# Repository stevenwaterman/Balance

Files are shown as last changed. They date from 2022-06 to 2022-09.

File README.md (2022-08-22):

# Balance Box

I built a box that lets me publicly share how I'm feeling.

[Read the blog post for more info](https://stevenwaterman.uk/balance-box)

## Instructions

These are going to be fairly vague, because you probably shouldn't follow my instructions directly.
Feel free to get in touch if you need help.

### Tools

- Soldering Iron
- 3D Printer, min 20x12x12cm bed
- Multimeter, unless you're a sadist

### Parts

Generic things:

- Breadboard jumper wires, male-male and male-female
- Wire
- Solder
- (Recommended) TriPad stripboard
  - Use whatever you're comfortable with for wiring up the shift registers and the resistors
- Approx 300g printer filament
  - I used PETG for the case and PLA for the sliders, anything will work

These are just the parts I used, alternatives will work

- 1x Arduino Uno & USB Cable
- 3x SN74HC595N shift registers
- 3x LDS-C814RI 7-segment displays
- 3x PTB0143-2010BPB103 slide potentiometers
- 21x 273-158-RC resistor, 158 ohm, 1/2 watt
- 4x M6 bolts, 30mm-ish length

### Steps

*This is from memory, no guarantees. Skip to the 'Firebase' section if you just want the website part.*

**Electronics:**

1. Print all the pieces in the `printerFiles` folder. It will take about 24hrs in multiple runs.
1. Put the 3 shift registers with resistors on the outputs on the stripboard. See `circuit.svg`.
1. Use male-female jumper cables to connect from the stripboard to the display, or plug the display into more stripboard.
1. Use male-male jumper cables to connect the 3 logic pins of the shift register to the arduino.
1. Solder wires to the display cathodes, and potentiometer power pins.
1. Solder a male-male jumper cable to the potentiometer signal pin.
1. Place the components into the housing, and bolt the face plate on to hold it together. The bolts should self-tap into the plastic.
1. Connect all the negatives together, and all the positives together, and plug them into the Arduino with a jumper cable.
1. Plug the display in with the jumper cables from before. The order doesn't really matter, just make sure it's consistent between them.
1. Plug everything in to the Arduino.
1. Put the back case on, bolt everything together
1. Add the 3d-printed sliders on the potentiometers. If your printer is dialed in, they should push-fit nicely.

**Arduino:**

1. Plug in the Arduino, update the pin configs to match your setup, and flash the provided sketch.
1. Swap the `LED` constants around until the numbers display correctly. See [the datasheet](https://eu.mouser.com/datasheet/2/244/LUMX_S_A0001418642_1-2551748.pdf) for a segment label reference.
1. Check that everything is working and you can see the current score in the Serial Monitor.

**Firebase:**

1. Create a [Firebase](https://console.firebase.google.com/) account and a new project.
1. Under the project settings, download the service account key, and save it as `credentials.json` in the root of this repository.
1. In the project settings, add a web app, and copy the `firebaseConfig` out of the `npm` SDK setup and configuration, into [web/src/lib/initFirebase.ts](https://github.com/stevenwaterman/Balance/blob/03ef952fb352bc81930753e494502babe5fda147/web/src/lib/initFirebase.ts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).
1. Enable Authentication.
1. Enable the Google sign-in provider for authentication
1. Add your domain (eg `stevenwaterman.uk` or `stevenwaterman.github.io` etc) to the `Authorized Domains` under `Settings`.
1. Enable Firestore.
1. Create three collections - `current`, `historic`, and `labels`.
1. Set the Firestore rules as:

```
rules_version = '2';
service cloud.firestore {
  match /databases/{database}/documents {
  	match /historic/{document=**} {
      allow read, write: if request.auth.uid == "sDV4cfFys0R5bapdvpeCTQSL9t32";
    }
    match /current/current {
      allow read: if true;
      allow write: if request.auth.uid == "sDV4cfFys0R5bapdvpeCTQSL9t32";
    }
    match /labels/{document=**} {
      allow read,write: if request.auth.uid == "sDV4cfFys0R5bapdvpeCTQSL9t32";
    }
  }
}
```

**Web:**

Start by forking this repository. It's mostly automated, other than a couple of bits of configuration.

1. Enable workflows under the `Actions` tab
1. In GitHub `Setting > Security > Secrets > Actions`, create a new Repository Secret named `FIREBASE_CREDENTIALS`. Copy the contents of the `credentials.json` file into the `Value` text box and save it.
1. If your repo is not called `Balance`, update the [base path](https://github.com/stevenwaterman/Balance/blob/03ef952fb352bc81930753e494502babe5fda147/web/svelte.config.js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) in `web/svelte.config.js`.
2. Update the fetch url with your GitHub username [in web/src/lib/dataSet.ts](https://github.com/stevenwaterman/Balance/blob/de5710807bf56cdf3094eda35e12951909dd7c2e/web/src/lib/dataSet.ts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)
3. The web app should automatically build, storing the static site in the `gh-pages` branch. You might have to give it permission to push to your repo.
4. Enable GitHub pages in the GitHub settings, selecting the `gh-pages` branch.
5. Wait for it to build, then go to `<YOUR_GH_USERNAME>.github.io/Balance` to verify it's all working.
6. Visit `<YOUR_GH_USERNAME>.github.io/Balance/control` and log in with google.
7. Visit the Firebase authentication page, and copy the UID for your use account.
8. Use that UID in the Firestore rules and update it [in web/src/routes/control.svelte](https://github.com/stevenwaterman/Balance/blob/03ef952fb352bc81930753e494502babe5fda147/web/src/routes/control.svelte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).

Wait for it to redeploy, and you should now be able to access the control page!

**Valid urls:**

- `/Balance`: Normal current-data display.
- `/Balance/graph`: Historic data display. Data updates once per day.
- `/Balance/control`: Data entry.

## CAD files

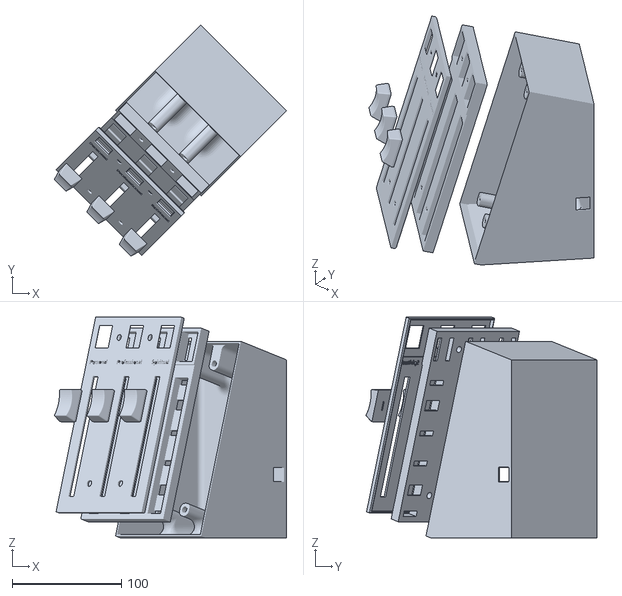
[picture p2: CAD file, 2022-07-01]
printerFiles/exploded.stl
212.1 x 211.0 x 201.9

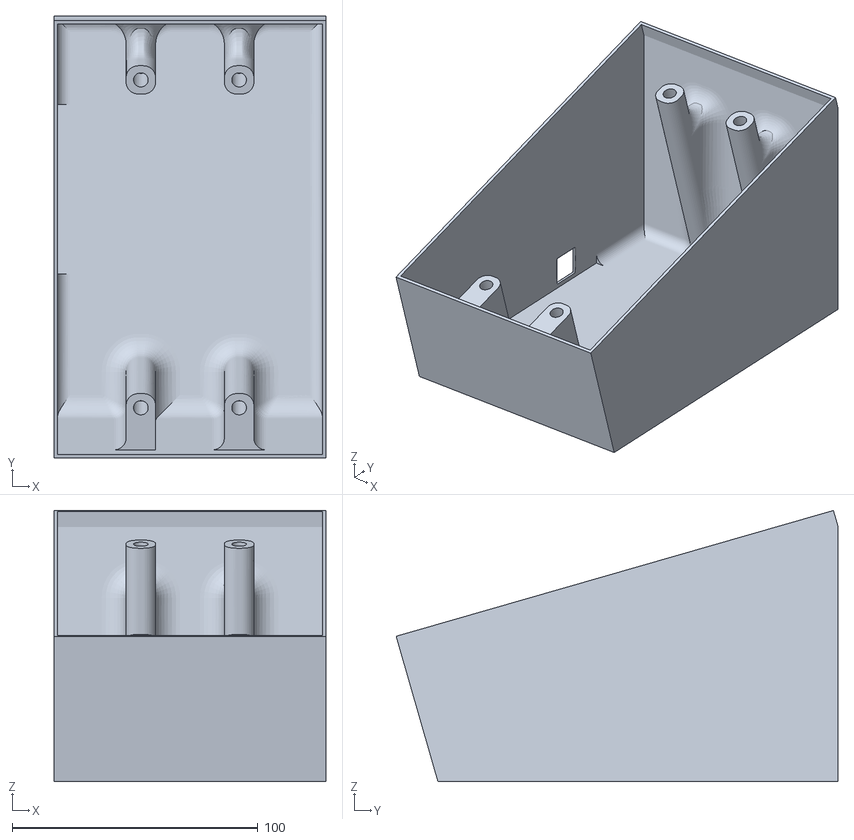
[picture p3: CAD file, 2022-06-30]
printerFiles/case.stl
110.7 x 179.8 x 110.3

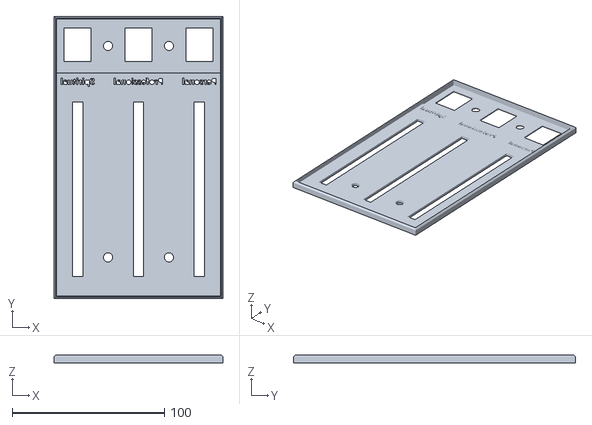
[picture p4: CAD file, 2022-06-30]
printerFiles/faceplate.stl
110.7 x 185.2 x 5.00

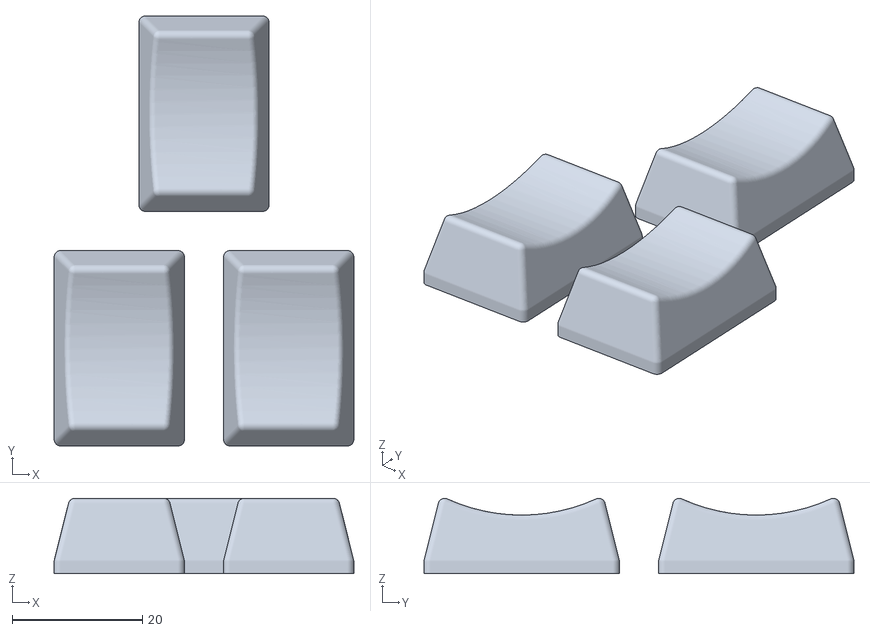
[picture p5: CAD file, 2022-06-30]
printerFiles/slider.stl
46.0 x 66.0 x 11.6

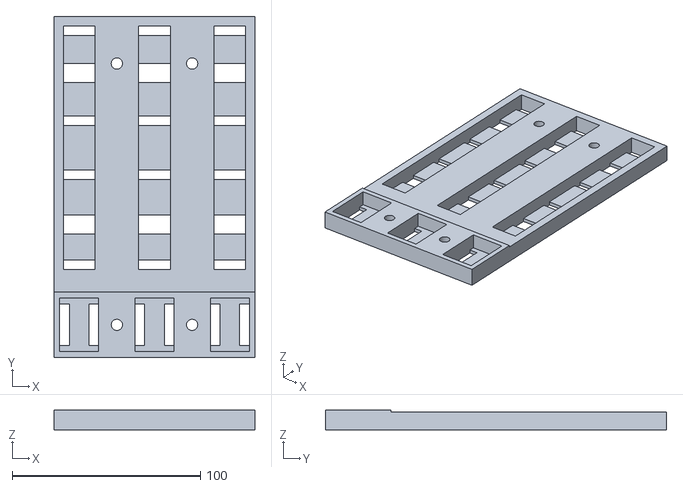
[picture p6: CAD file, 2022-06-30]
printerFiles/housing.stl
106.7 x 181.2 x 10.5

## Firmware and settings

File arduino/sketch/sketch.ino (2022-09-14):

int serenityLatch = 2;
int growthLatch = 5;
int belongingLatch = 8;

int serenityData = 3;
int growthData = 6;
int belongingData = 9;

int serenityClock = 4;
int growthClock = 7;
int belongingClock = 10;

int serenityPot = A5;
int growthPot = A4;
int belongingPot = A3;

int led_a = 2;
int led_b = 16;
int led_c = 64;
int led_d = 128;
int led_e = 8;
int led_f = 4;
int led_g = 32;

int led_0 = led_a + led_b + led_c + led_d + led_e + led_f;
int led_1 = led_b + led_c;
int led_2 = led_a + led_b + led_d + led_e + led_g;
int led_3 = led_a + led_b + led_c + led_d + led_g;
int led_4 = led_b + led_c + led_f + led_g;
int led_5 = led_a + led_c + led_d + led_f + led_g;
int led_6 = led_a + led_c + led_d + led_e + led_f + led_g;
int led_7 = led_a + led_b + led_c;
int led_8 = led_a + led_b + led_c + led_d + led_e + led_f + led_g;
int led_9 = led_a + led_b + led_c + led_d + led_f + led_g;

int digits[10] = {led_0, led_1, led_2, led_3, led_4, led_5, led_6, led_7, led_8, led_9};
int dash = led_g;

void setup() {
    Serial.begin(9600);
  
    pinMode(serenityLatch, OUTPUT);
    pinMode(growthLatch, OUTPUT);
    pinMode(belongingLatch, OUTPUT);
    
    pinMode(serenityData, OUTPUT);
    pinMode(growthData, OUTPUT);
    pinMode(belongingData, OUTPUT);
    
    pinMode(serenityClock, OUTPUT);
    pinMode(growthClock, OUTPUT);
    pinMode(belongingClock, OUTPUT);
    
    display(-1, serenityLatch, serenityClock, serenityData);
    display(-1, growthLatch, growthClock, growthData);
    display(-1, belongingLatch, belongingClock, belongingData);
}

int serenityDisplay = 0;
int serenitySlider = 0;

int growthDisplay = 0;
int growthSlider = 0;

int belongingDisplay = 0;
int belongingSlider = 0;

void loop() {
  bool changed = false;
  
  int newSerenitySlider = read(serenityPot);
  if (newSerenitySlider != -1 && serenitySlider != newSerenitySlider) {
    changed = true;
    serenityDisplay = newSerenitySlider;
    serenitySlider = newSerenitySlider;
    display(serenityDisplay, serenityLatch, serenityClock, serenityData);
  }

  int newGrowthSlider = read(growthPot);
  if (newGrowthSlider != -1 && growthSlider != newGrowthSlider) {
    changed = true;
    growthDisplay = newGrowthSlider;
    growthSlider = newGrowthSlider;
    display(growthDisplay, growthLatch, growthClock, growthData);
  }

  int newBelongingSlider = read(belongingPot);
  if (newBelongingSlider != -1 && belongingSlider != newBelongingSlider) {
    changed = true;
    belongingDisplay = newBelongingSlider;
    belongingSlider = newBelongingSlider;
    display(belongingDisplay, belongingLatch, belongingClock, belongingData);
  }

  if (changed) {
    char strBuf[3];
    sprintf(strBuf, "%d%d%d", serenityDisplay, growthDisplay, belongingDisplay);
    Serial.println(strBuf);
  }

  if (Serial.available() > 0) {
    String dataString = Serial.readStringUntil('\n');
    
    serenityDisplay = dataString[0] - '0';
    growthDisplay = dataString[1] - '0';
    belongingDisplay = dataString[2] - '0';

    display(serenityDisplay, serenityLatch, serenityClock, serenityData);
    display(growthDisplay, growthLatch, growthClock, growthData);
    display(belongingDisplay, belongingLatch, belongingClock, belongingData);
  }

  delay(16);
}

int read(int potPin) {
  int sensorValue = analogRead(potPin);

  for (int i = 0; i < 10; i++) {
    if (sensorValue < i * 110 + 85) {
      return 9 - i;
    }
 
    if (sensorValue < i * 110 + 105) {
      return -1;
    }
  }

  return -1;
}

void display(int digit, int latchPin, int clockPin, int dataPin) {
  digitalWrite(latchPin, LOW);
  
  if (digit < 0 || digit > 9) {
    shiftOut(dataPin, clockPin, MSBFIRST, dash);
  } else {
    shiftOut(dataPin, clockPin, MSBFIRST, digits[digit]);
  }
  
  digitalWrite(latchPin, HIGH);
}

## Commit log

2022-06-29 Add arduino code
2022-06-30 Add STL files
    [case.STL, exploded.STL, faceplate.STL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]
2022-06-30 Move printer files
    [case.STL, exploded.STL, faceplate.STL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]
2022-06-30 Tidy up STL files
    [case.STL, case.stl, exploded.STL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]
2022-06-30 Add instructions for adding the case and the sliders
2022-07-01 Rotate exploded model
    [exploded.stl]
2022-07-29 Fix control by triggering onSnapshot during mount and not reactively
2022-09-14 Change moods that I track away from balance scores
